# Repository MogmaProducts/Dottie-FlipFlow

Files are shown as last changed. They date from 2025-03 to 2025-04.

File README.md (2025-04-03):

# Dottie FlipFlow


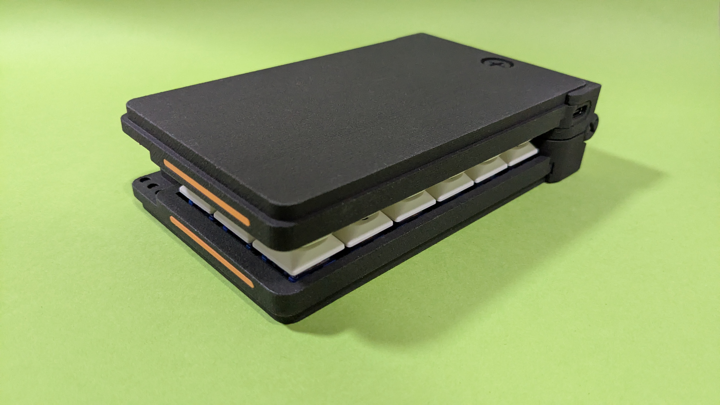
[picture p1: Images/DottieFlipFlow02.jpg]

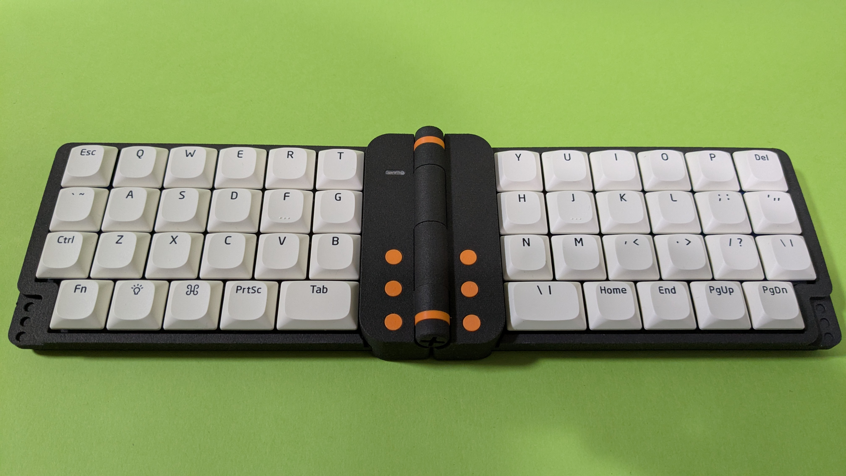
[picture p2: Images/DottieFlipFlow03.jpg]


[ShopSite](https://mogma-products.booth.pm/items/6564751)

## What's Dottie FlipFlow
- The keyboard has a hinge in the center, allowing it to fold up.
- It is thin and can be equipped with Choc V1, V2, and Lofree key switches.
- This keyboard only supports lowprofile keycaps.
- We are very sorry, but this keyboard is not released as open source.

## What is this repository?
- This is a repository for publishing files and manuals required by users.

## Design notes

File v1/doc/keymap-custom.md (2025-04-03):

# キーマップの設定

キーマップの設定はRemapで行います。  

1. Dottie FlipFlowをPCに接続します。

1. ブラウザより以下のサイトにアクセスしてください。  
https://remap-keys.app/configure

## 初回やること
初回アクセスの場合はキーボードへの接続が必要となるため、Dottie FlipFlowを選択して接続を行ってください。
1. `+キーボード` をクリック
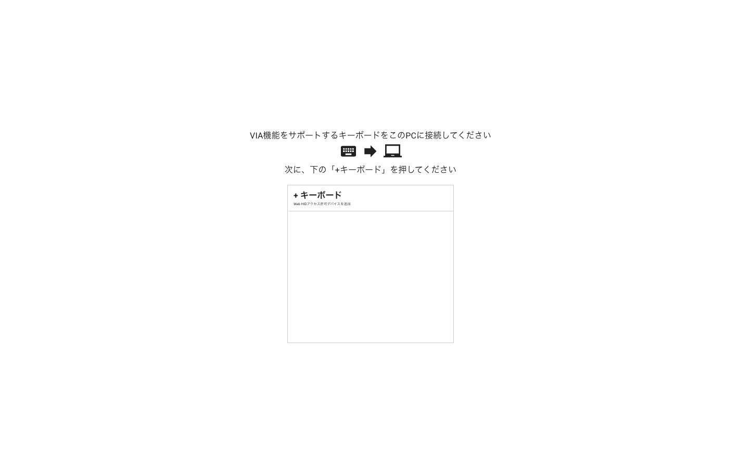
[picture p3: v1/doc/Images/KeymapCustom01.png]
初回アクセスの画面

1. `mogma_products/dottie_flipflow` を選択して`接続`をクリック
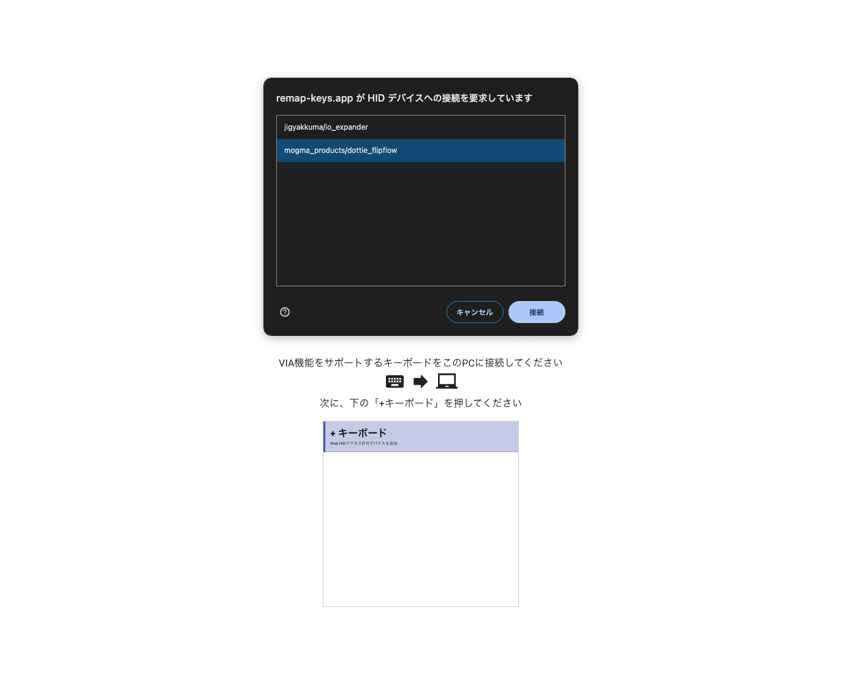
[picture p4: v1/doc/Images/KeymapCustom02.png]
デバイス選択


## キーマップ設定
1. キーコンフィグ画面が開いたらお好みのキーマップに変更してください。
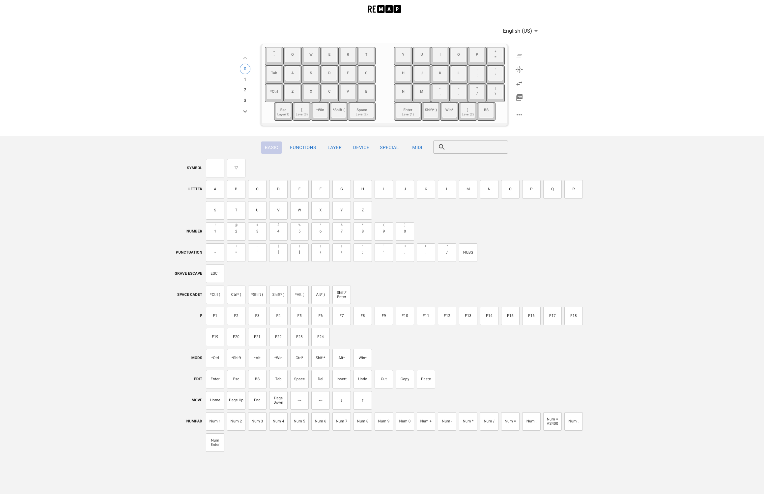
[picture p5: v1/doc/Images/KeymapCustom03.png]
キーコンフィグ画面


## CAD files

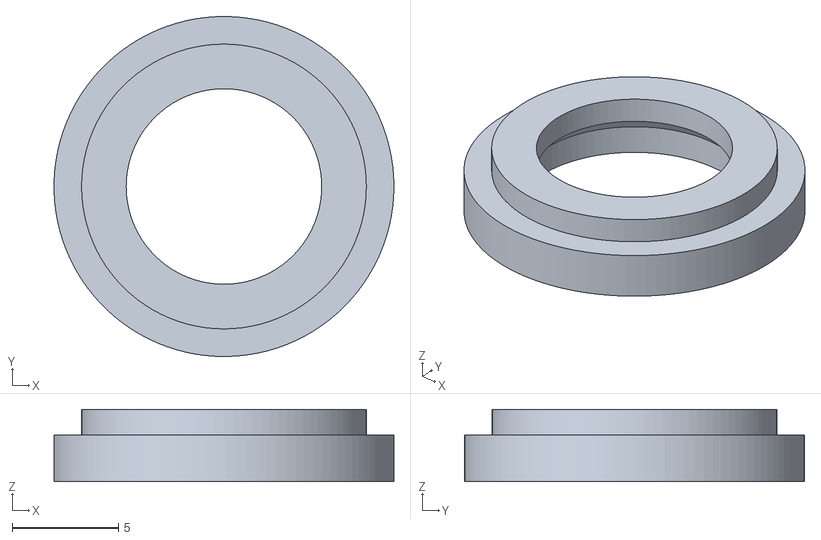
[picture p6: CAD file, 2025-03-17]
v1/Accessories/Dottie_ring_standoff.stl
16.0 x 16.0 x 3.40

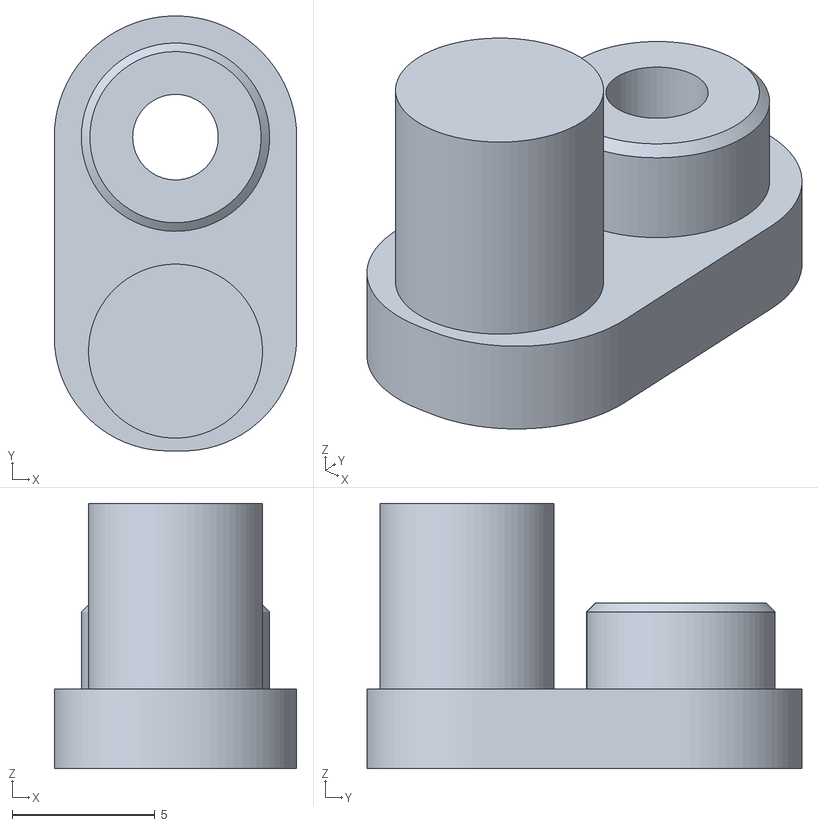
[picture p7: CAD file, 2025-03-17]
v1/Accessories/Dottie_dots_bit.stl
8.50 x 15.2 x 9.30

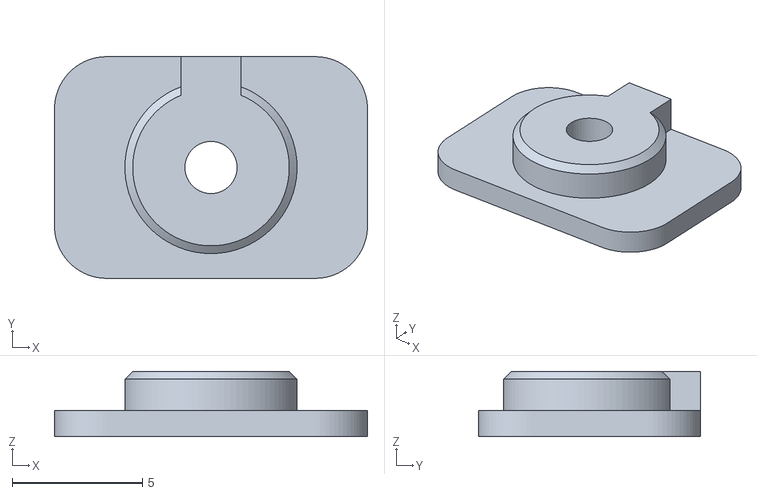
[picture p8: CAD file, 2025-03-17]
v1/Accessories/Dottie_dots_cover.stl
12.0 x 8.50 x 2.50

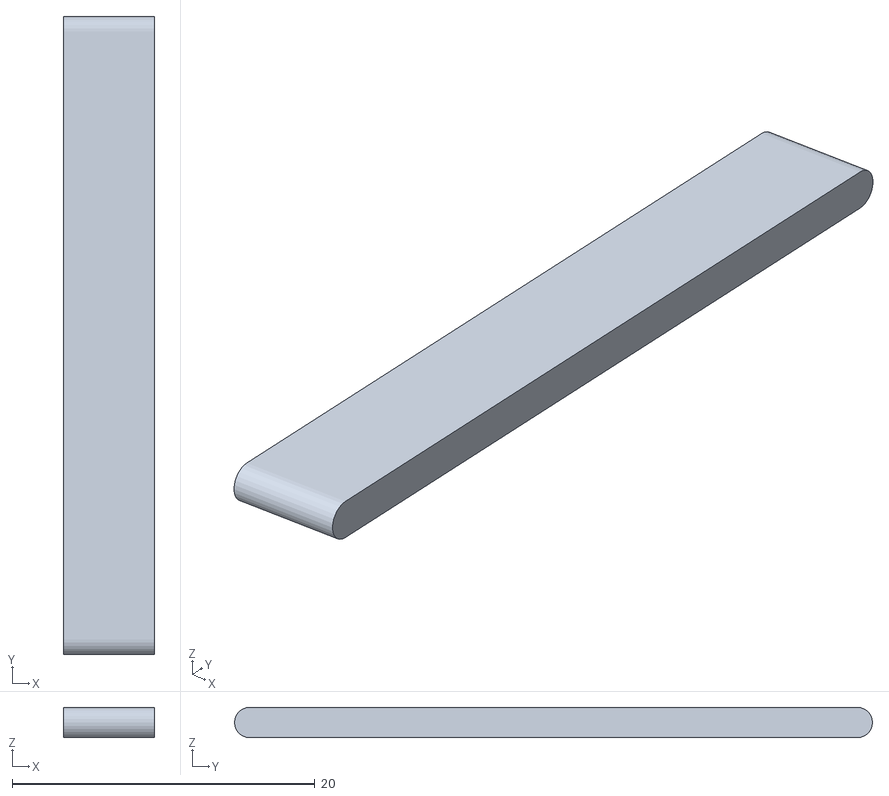
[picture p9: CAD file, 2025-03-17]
v1/Accessories/Dottie_sideline.stl
6.00 x 42.1 x 2.00

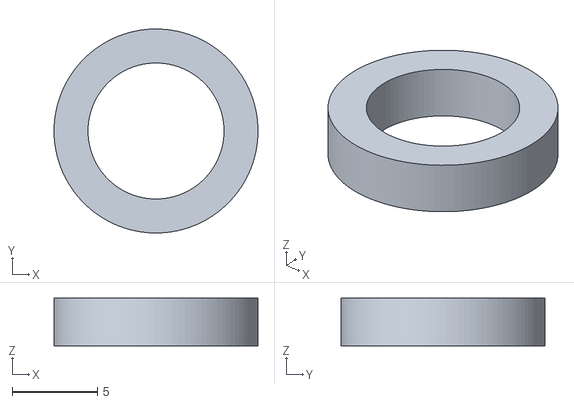
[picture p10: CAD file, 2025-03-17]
v1/Accessories/Dottie_washer.stl
12.0 x 12.0 x 2.80

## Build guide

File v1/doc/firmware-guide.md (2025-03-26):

# ファームウェアの設定

## ファームウェア

ビルド済ファームウェア
https://github.com/MogmaProducts/Dottie-FlipFlow/tree/main/v1/file

ビルドするためのソースコード
https://github.com/MogmaProducts/qmk_firmware/tree/keyboard/dottie-flipflow

## 購入後のRP2040 Zeroにビルドファイルを書き込む

購入して何もQMKのファームウェアが書き込まれていない場合は以下の手順で書き込みを行ってください。

1. ビルド済ファームウェアを作業するPCにダウンロードする。
1. RP2040 ZeroのBOOTボタン(並んでいるボタンの左側)を押しながらPCに接続されているUSBケーブル(Type-C)を接続する。
1. USBストレージとして認識されたのが確認できたらビルド済ファームウェアに保存する。
1. ファイル格納後、USBキーボードとして認識されることを確認する。

## ビルドファイルを書き換える

手順としては[購入後のRP2040 Zeroにビルドファイルを書き込む](#購入後のrp2040-zeroにビルドファイルを書き込む)と同様ですが、ファームウェアを書き込んだ後はRP2040 Zeroではなく、**キーボードの左1.5Uキーを押しながらUSBケーブルを差し込む**ことでUSBストレージとして起動します。  
ケースから出すことなくBOOT出来るので少し楽ができます。

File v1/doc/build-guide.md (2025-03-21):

# Dottie FlipFlow V1 ビルドガイド
## パーツリスト
### 共通パーツ
| Parts | Amount | Description |
| --- | --- | --- |
| PCB | 左右1枚ずつ |　キースイッチを取り付ける基板 |
| 本体ケース | 左右1つずつ | PCBを収納するケース |
| ケースヒンジ | 左右1つずつ | 左右の本体ケースをつなぐヒンジ |
| ヒンジスクリュー | 2 | ヒンジの接合部品 |
| ボトムスクリュー | 2 |　本体ケースとケースヒンジの接合部品 |
| SHケーブル | 1 | 左右PCBを接続するケーブル |
| LEDディフューザー | 1　| LEDを透過させるクリアパーツ |
| ヒンジワッシャー | 各色2 | ヒンジとヒンジスクリューに挟むワッシャー兼装飾部品 |
| ケーススペーサー | 各色2 | ケースとPCBの間に入れるスペーサー兼装飾部品 |
| マグネットDots | 各色6 | ヒンジ上部に仕込むマグネットのフタ兼装飾部品 |
| マグネットカバー | 2 | ヒンジ横に仕込むマグネットのフタ |
| サイドバー | 各色2 | ケースベゼルのスリットに差し込む装飾部品 |
|マグネット | 8 | 6 x 2 mmのマグネット |

※付属のマグネットは磁力が弱いため、100円ショップなどで購入いただくのをおすすめします。

### Standardキット(はんだ付けが必要)に含まれるパーツ
Easyキット(はんだ付け済のキット)はこれらのパーツは既にはんだ付けされているため、パーツとしては同梱されていません。
| Parts | Amount | Description |
| --- | --- | --- |
| RP2040 Zero(相当品) | 1 | マイコン |
| Kailh Choc ホットスワップソケット | 50 | キースイッチを脱着可能にするためのソケット |

### 使用者で用意するもの
| Parts | Amount | Description |
| --- | --- | --- |
| キースイッチ | 46 | Kailh Choc V1,V2, Lofree Low Profileのいずれかに対応したもの |
| キーキャップ | 1U x 44, 1.5U x 2 | Low Profileのキーキャップのみ対応 |
| ゴム足 | 8 | 装着しなくても使えますが、好みに応じてゴム足を貼り付けてください |
| USBケーブル | 1 | キーボード側はUSB Type-Cが必要 |

### 組み立てに必要な工具
| Tool | Description |
| --- | --- |
| プラスドライバー | 軸が5.5〜7mmくらいのもの |
| ニッパーもしくはカッターナイフ | PCBを切り取るために使用 |
| やすり | PCBを削るために使用 |
| ピンセット | 細かい部品をつまんだり通電確認用にあると便利 |

## 組み立てる前に
### 注意事項
- 本キーボードはヒンジ部と底面部に3Dプリント製のネジを採用していますが、強く締めるとネジ部分が固く締まったりケースが破損する可能性がありますのでご注意ください。
- 本キーボードに強い衝撃を加えると破損する恐れがあるため、特に持ち運びの際にはご注意ください。
- Standard Kitにおいても一部の部品が既にはんだ付けされていますので、はんだ付け作業の際ははんだゴテではんだ付け済みの部品に触れないように注意してください。
- 市販品のパーツ(RP2040 Zero(相当品)、ホットスワップソケット)はサービスとして添付しておりますので、万が一不良があった場合は購入者様にてご用意をお願いします。
- キーボードケースなどのSLSによる3Dプリントの部品は製造プロセス上、原料の粉末が付着している可能性があるため、その場合は布なので拭き取ってください。
- SLSによる3Dプリントの部品は形状の関係で反りなどの歪みがある場合がありますが、使用上問題ない精度であると確認したものを販売しています。気になる場合はドライヤーやヒートガンなどで温めて歪みを修正してください。

## ビルド手順
Easy Kitを購入の方ははんだ付けの手順は飛ばして本体組み立てに進んでください。

### はんだ付けの前の準備
はんだ付けの前に動作確認を行います。はんだ付けをした後に動作不良が発覚した場合、手戻りの作業に大きく時間を取られてしまうためです。  

1. RP2040 Zeroを取り出し、BOOTボタンを押下しながらPCに接続したUSBケーブル(Type-C)を接続します。
1. USBストレージとして認識されることを確認します。
1. RPI-RP2と認識されたUSBストレージにビルド済みファイルを保存します。
1. 再起動後にLEDが点灯すれば動作確認と下準備は完了です。

### はんだ付け
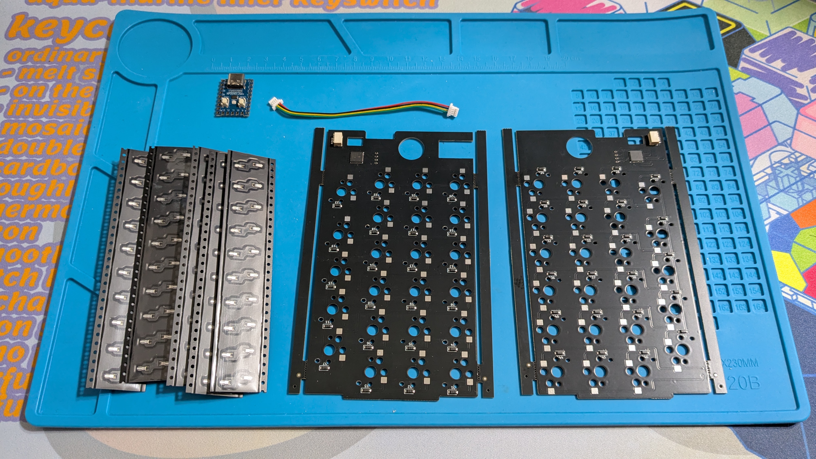
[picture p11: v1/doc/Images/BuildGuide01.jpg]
はんだ付け作業で使うもの

1. PCBの不要な部分を切り取ります。工具を使わずに切り取ることも出来ますが、ニッパーなどで切り取るときれいに仕上がります。
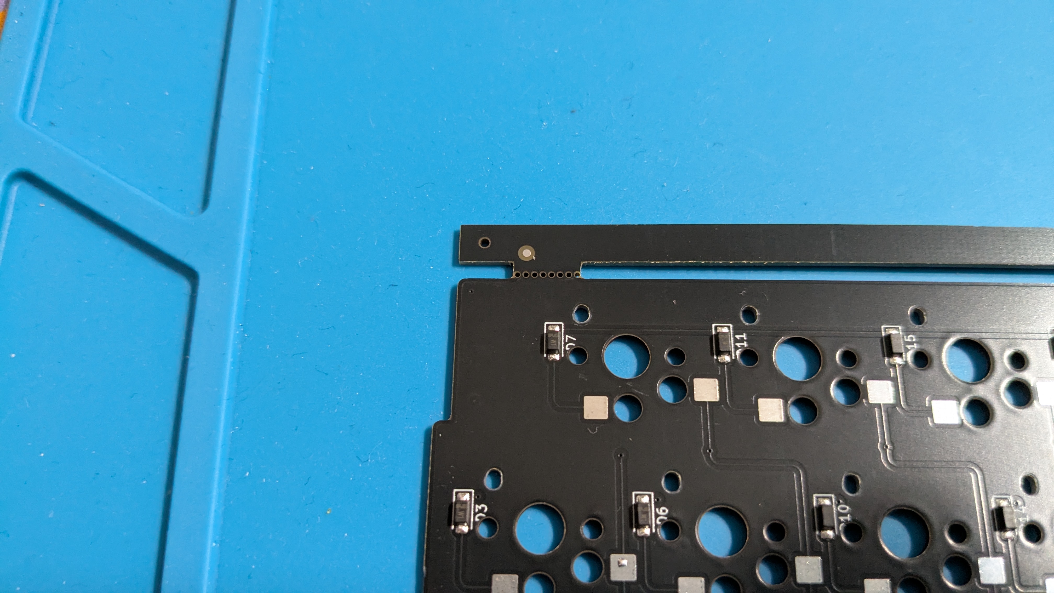
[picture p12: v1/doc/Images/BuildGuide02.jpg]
切り取る前

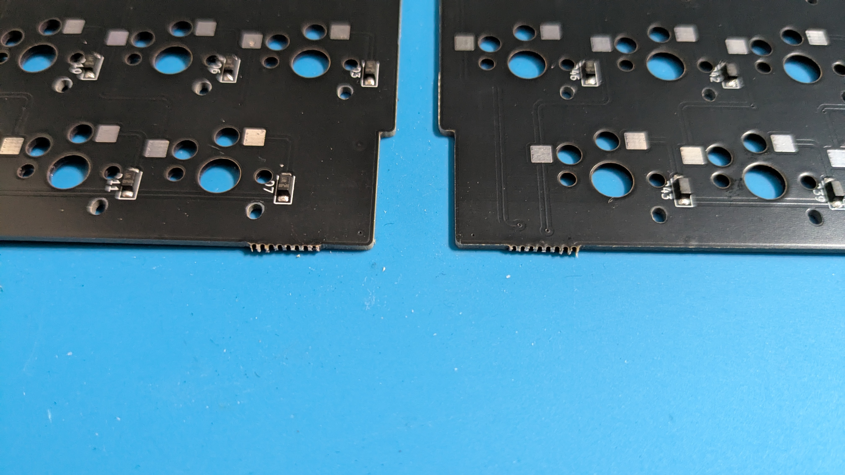
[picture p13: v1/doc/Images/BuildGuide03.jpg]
切り取った後

1. 切断面をやすりで削ります。ある程度削れていればよいです。
削った後
1. ホットスワップソケットのはんだ付けをします。はじめに、注意点としてソケットには向きがあります。角がある方が外側(つまりは左側)に来るようにはんだ付けします。
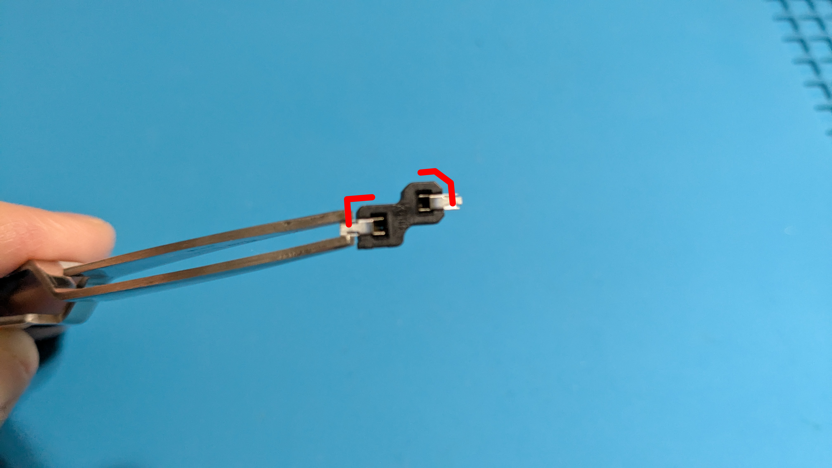
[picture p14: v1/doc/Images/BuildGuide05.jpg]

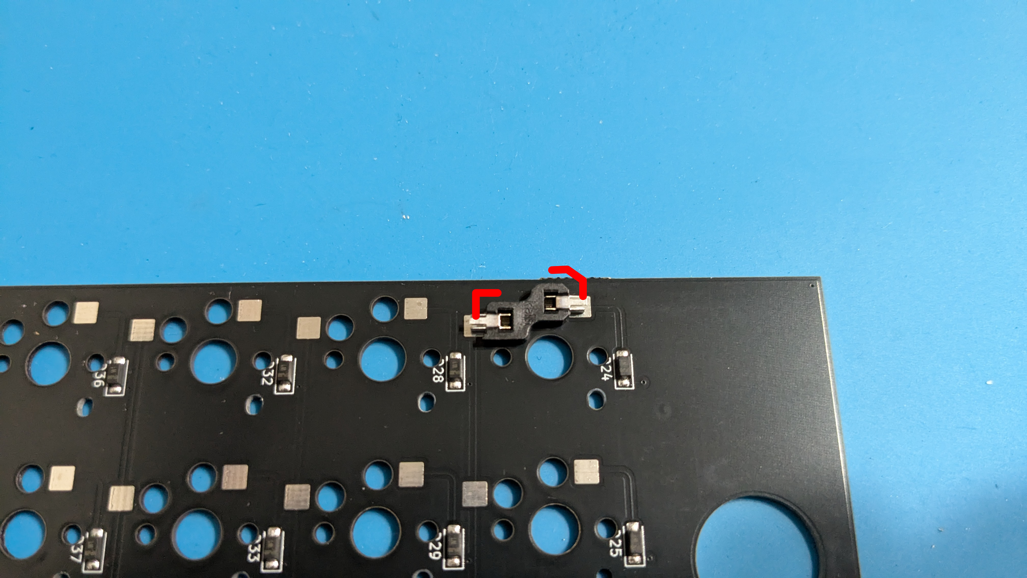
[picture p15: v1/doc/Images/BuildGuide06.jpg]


1. ホットスワップソケットをPCBに並べます。ホットスワップソケットはPCB裏面にはんだ付けします。


1. ホットスワップソケットの両サイドをはんだ付けします。  
コツとしては片側だけはんだ付けした後に乗せたはんだを再加熱してホットスワップソケットを押さえるとしっかりとはんだ付けができます。  
両サイドを先にはんだ付けしてしまうと浮いていた場合に修正が難しいので片側ずつ丁寧にはんだ付けを行います。
Right側の裏面
Left側の裏面
この写真だとすべてをはんだ付けしてから浮いていないか確認していますが、これは間違いです。慣れないうちは1つ1つ確認しながらはんだ付けを行います。
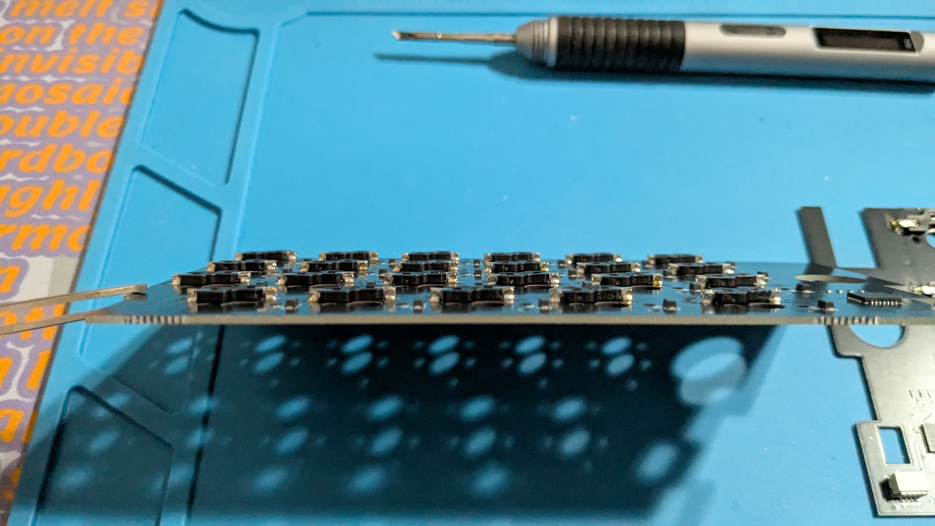
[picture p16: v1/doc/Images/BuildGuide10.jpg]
浮いてないか角度を変えてしっかり確認


1. RP2040 Zeroをはんだ付けします。RP2040 ZeroはPCB表面にはんだ付けしてください。  
はんだ付けをする位置は意図的にずらしているので画像を参考に配置してください。
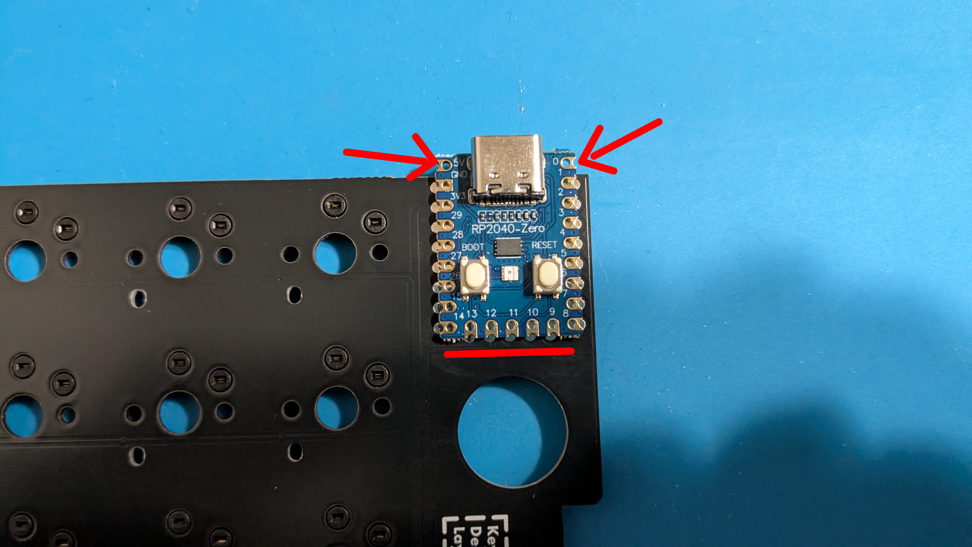
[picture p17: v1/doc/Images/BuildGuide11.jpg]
矢印の箇所はPCBに乗せない、おしりの部分に合わせる

1. クリアランスを確認するために1箇所だけはんだ付けし、その後ケースに入れてUSBコネクタが干渉しないか確認してください。  
干渉する場合は位置調整をしてください。
コンパクトの代償にクリアランスが厳しくてごめんなさい
1. 位置が確定したら残りの部分もはんだ付けします。
使用するIOが少ないので画像では全部ははんだ付けしてません

はんだ付けの作業はここで終了です。続きまして本体の組み立てです。

### 本体組み立て

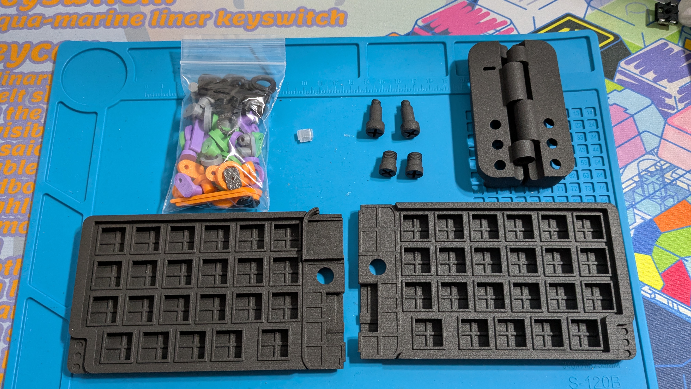
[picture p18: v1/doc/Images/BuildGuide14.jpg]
本体の組み立て作業で使うもの

1. ケースヒンジ(左側)を裏返し、LEDディフューザーを差し込みます。抜けないようクリアランスがシビアになっているため破損させないようゆっくりと押し込んでください。
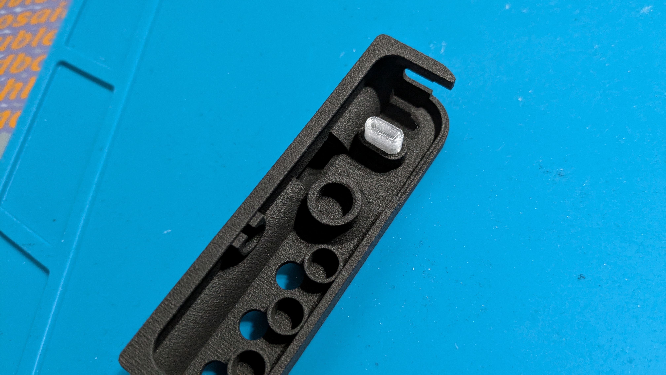
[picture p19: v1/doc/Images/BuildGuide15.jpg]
固いのでグッと押し込みます


1. ヒンジスクリューにヒンジワッシャーを差し込みます。  
ヒンジワッシャーは色違いを用意していますのでお好きなカラーをお選びください。
グッと押し込みます

1. 左右のケースヒンジを組み合わせ、ヒンジスクリューで止めます。  
このとき、強く締めないでください！ヒンジ部はネジの圧力によって破損する恐れがあるので、ヒンジを開閉させながら締め具合を微調整してください。

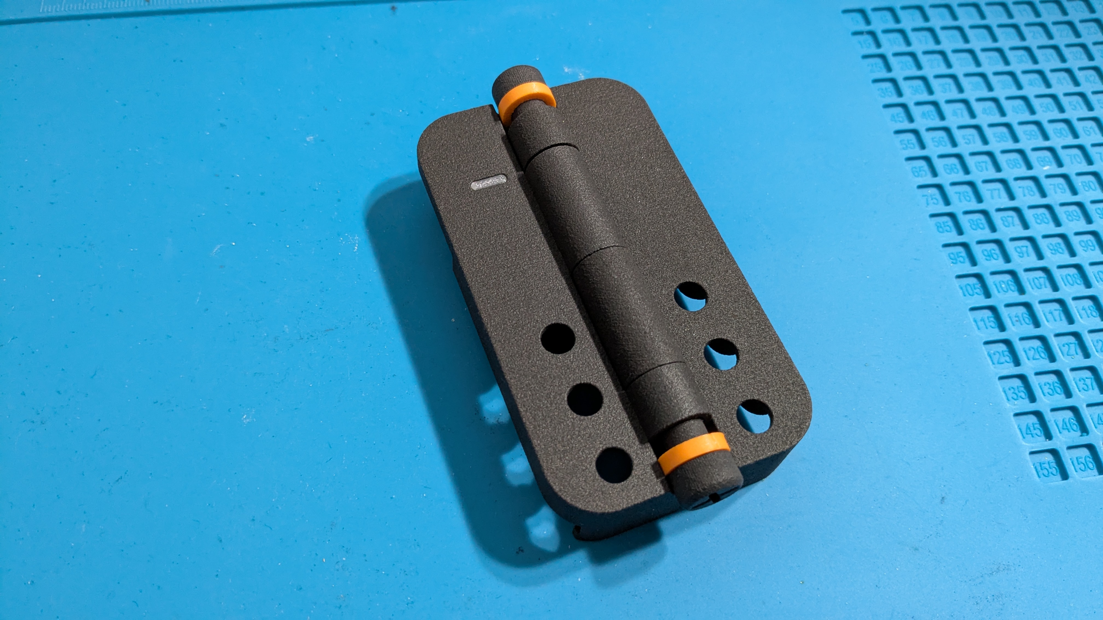
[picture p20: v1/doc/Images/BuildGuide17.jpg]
ヒンジスクリューを優しく締めます

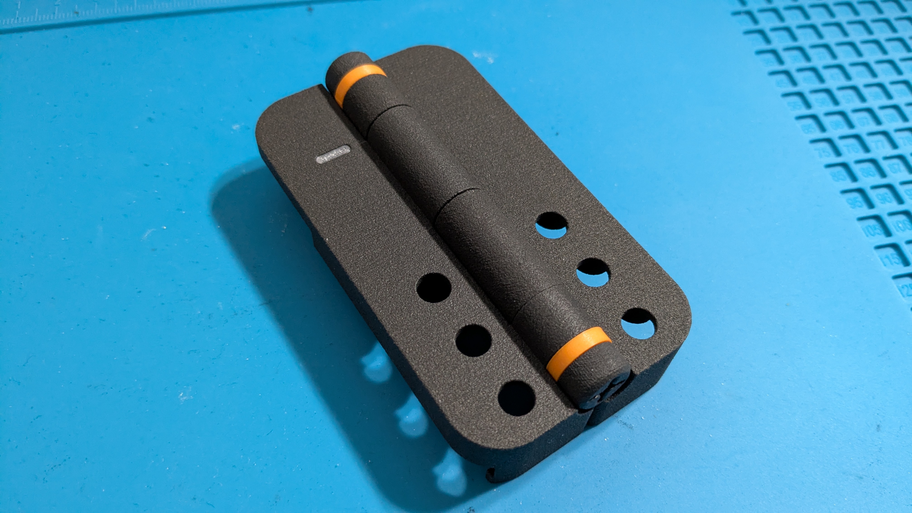
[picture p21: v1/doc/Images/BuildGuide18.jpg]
フェザータッチで締めてください


1. マグネットDotsを取り付けます。このとき、マグネットがある場合は先に赤丸の箇所にマグネットを入れてからマグネットDotsを取り付けてください。  
マグネットを利用する場合は磁力でくっつくよう方向を確認しながら入れてください。
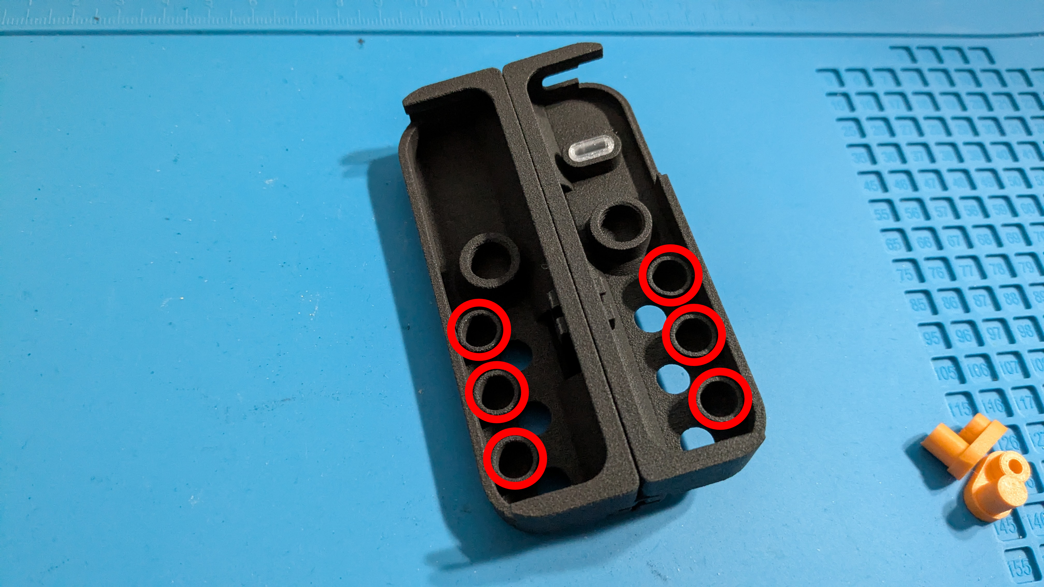
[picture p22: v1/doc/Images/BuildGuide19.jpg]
赤丸はマグネットを入れる箇所

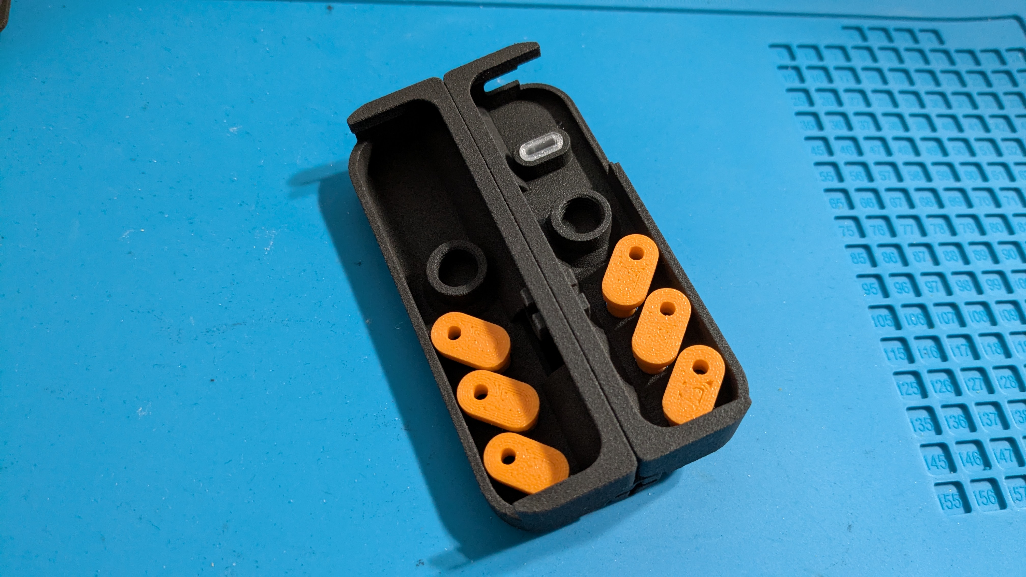
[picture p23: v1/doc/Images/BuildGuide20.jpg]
お好きなカラーのマグネットDotsをお選びください

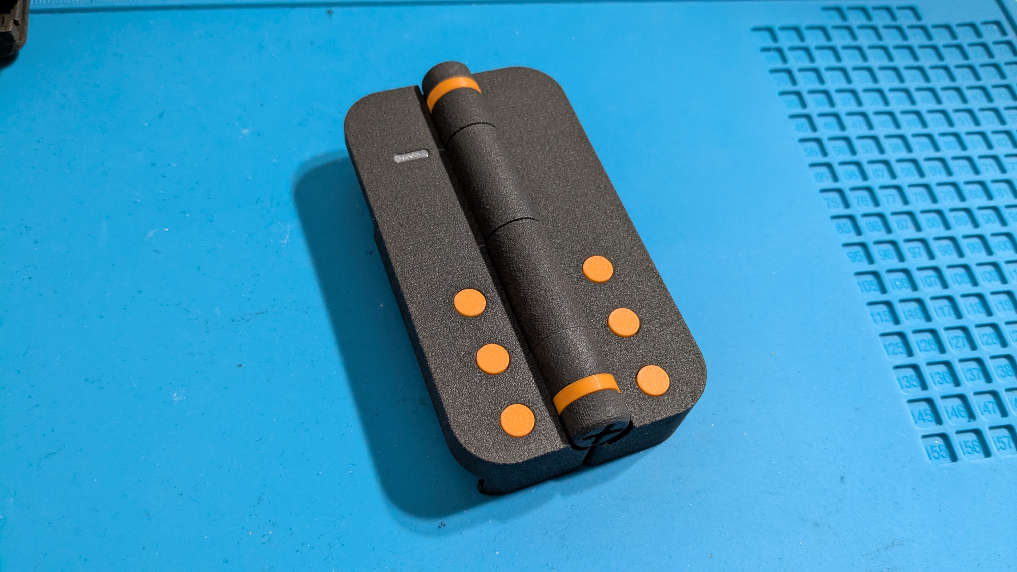
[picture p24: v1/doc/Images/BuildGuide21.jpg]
表面からみるとこんな感じ


1. ケースヒンジの横部にマグネットカバーを取り付けます。このとき、マグネットがある場合は先に赤丸の箇所にマグネットを入れてからマグネットカバーを取り付けてください。  
マグネットを利用する場合は磁力でくっつくよう方向を確認しながら入れてください。
赤丸はマグネットを入れる箇所
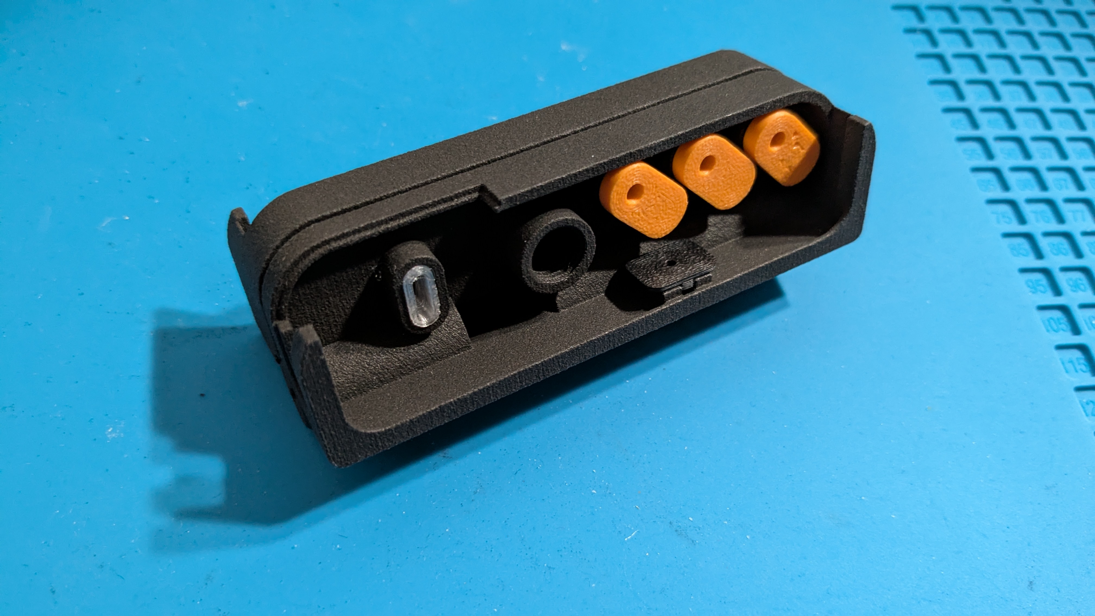
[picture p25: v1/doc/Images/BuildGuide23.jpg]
マグネットカバーを装着するとこんな感じ


1. サイドバーを装着します。ケースサイドのスリットはサイドバーを装着しなくても見栄えがいいのでこちらについてはお好みで装着してください。  
装着する場合はサイドバーをスリットの形状に合わせて押し込みます。

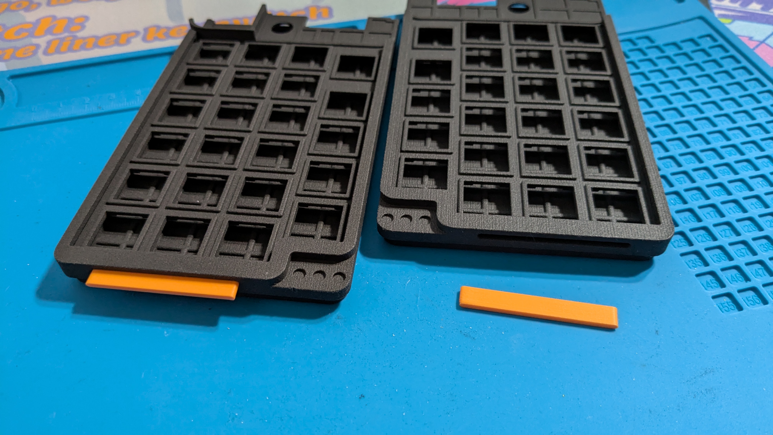
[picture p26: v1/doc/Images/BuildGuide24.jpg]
軽く差し込んでから

グッと押し込む

1. SHケーブルをPCBに差し込みます。その前に、差し込むコネクタの向きを確認します。  
SHケーブルのコネクタは金具が見えている面とプラスチック面がありますが、写真にある通りプラスチック面がみえるように差し込みます。
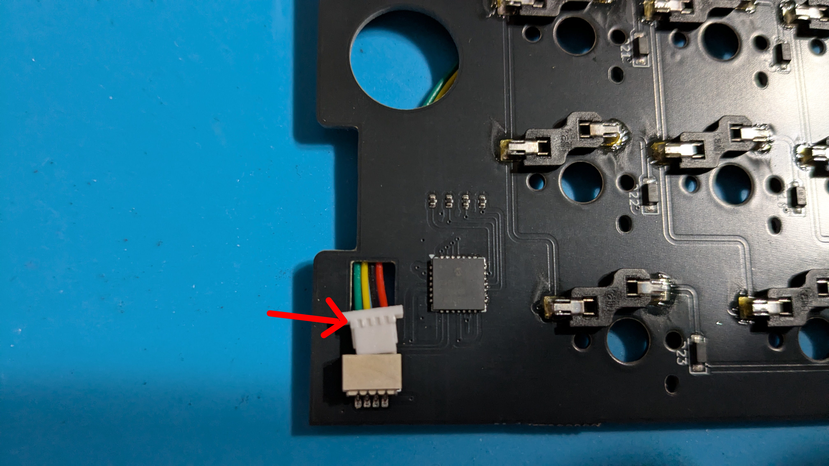
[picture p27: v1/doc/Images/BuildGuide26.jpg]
差し込む向きを間違えると故障の恐れがあるため注意が必要です

向きがあってるとしっかりと刺さります
PCBの左側にSHケーブルを差し込んでからケーススペーサーを乗せます。ケーブルを差し込みましたら四角のホールにケーブルを通しておきます。
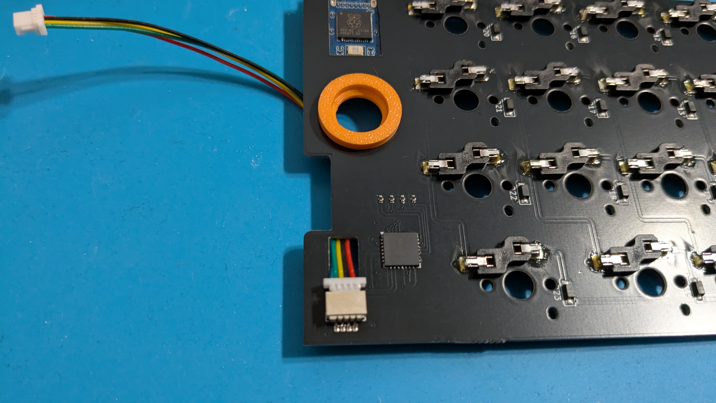
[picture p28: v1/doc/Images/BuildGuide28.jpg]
お好きなカラーのケーススペーサーをお選びください


1. PCBを置いたまま本体ケース(左側)をPCBに差し込みます。一気に差し込むのではなく2/3くらいまで差し込んでください。  
このとき、本体ケースにPCBが入りづらい場合は何度か抜き差しをして馴染ませてください。もしくはPCBの切り取り箇所が引っかかっていないかも合わせて確認してください。


1. PCBを本体ケース奥まで差し込みます。ケーススペーサーがズレていないことも確認してください。
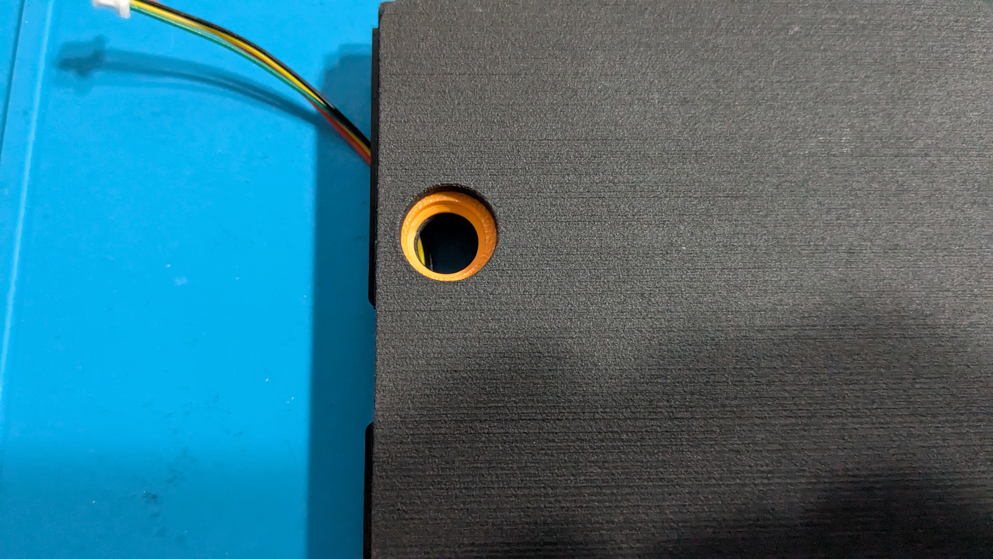
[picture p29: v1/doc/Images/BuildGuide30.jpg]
奥まで差し込むとケーススペーサーと本体ケースの穴の位置が合います

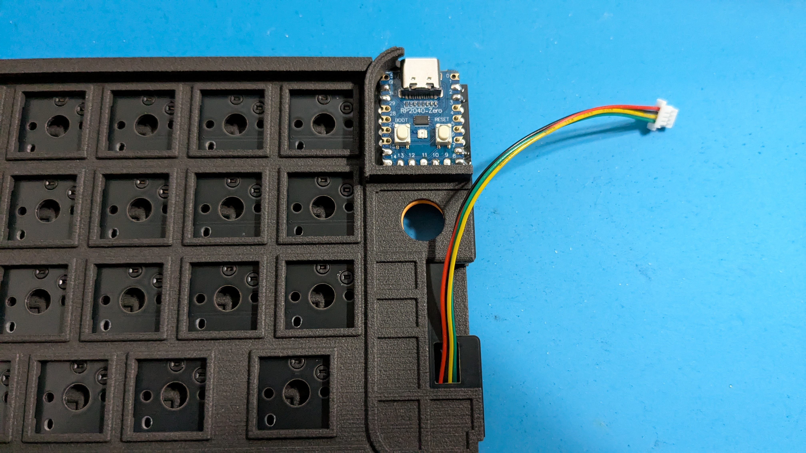
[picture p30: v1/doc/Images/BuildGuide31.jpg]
ケーブルを挟み込んでいないか表面からも確認する


1. SHケーブルをケースヒンジ内に通します。赤囲み箇所の切り欠きにケーブルを挿入します。
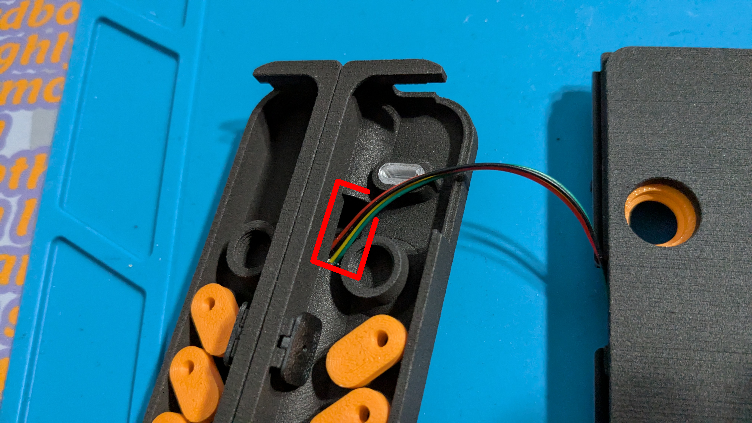
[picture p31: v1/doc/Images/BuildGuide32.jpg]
ほんとにケーブル通るの？となりそうですが、とりあえず突っ込んでみる

ケーブルが反対側から出ていることを確認します。うまく出てこない場合はピンセットなどでやさしく引き上げてください。  
強くひっぱるとコネクタ部分が破損するので注意してください。
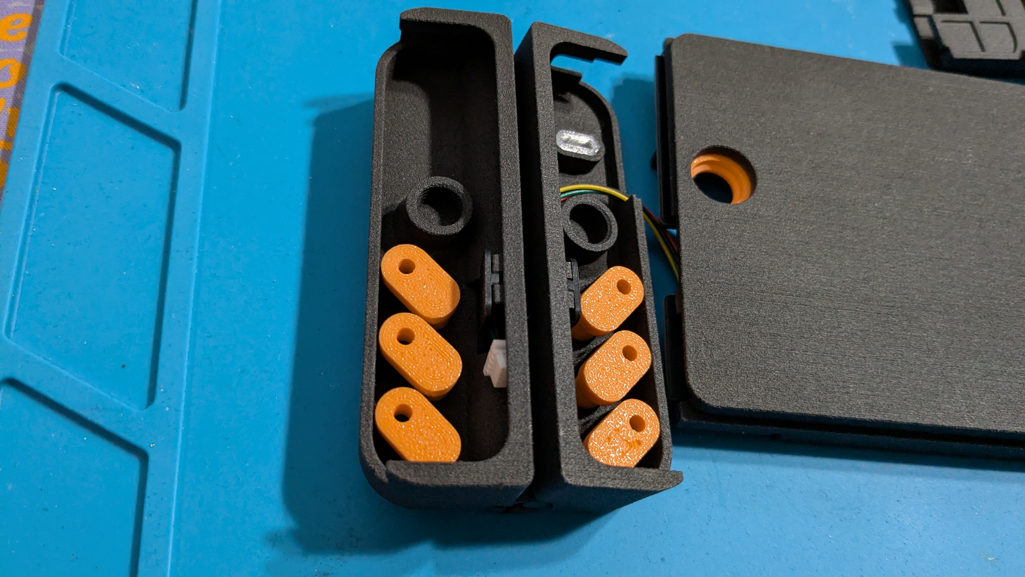
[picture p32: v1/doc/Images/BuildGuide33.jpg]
意外とコネクタがスッと出てくる


1. SHケーブルが反対側に通ったら本体ケースとケースヒンジに差し込みます。このとき、ケーブルが抜けないよう注意しながら本体ケースを差し込んでください。
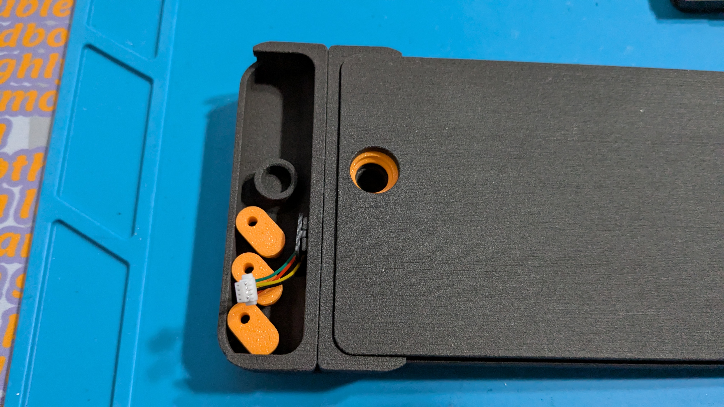
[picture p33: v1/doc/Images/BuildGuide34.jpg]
合体っっ！！！


1. 本体ケースにボトムスクリューで止めます。ヒンジスクリューと同様、締めすぎに注意してください。
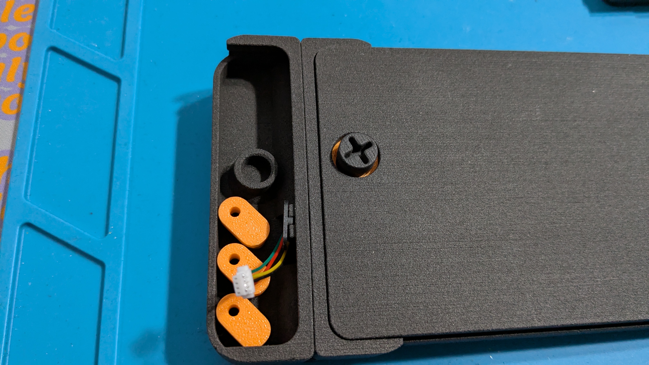
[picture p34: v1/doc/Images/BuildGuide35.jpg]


1. PCB(右側)にSHケーブルを差し込みます。左側と同様、プラスチック面がみえるようにして差し込んでください。ケーブルを差し込んだらケーススペーサーを置きます。
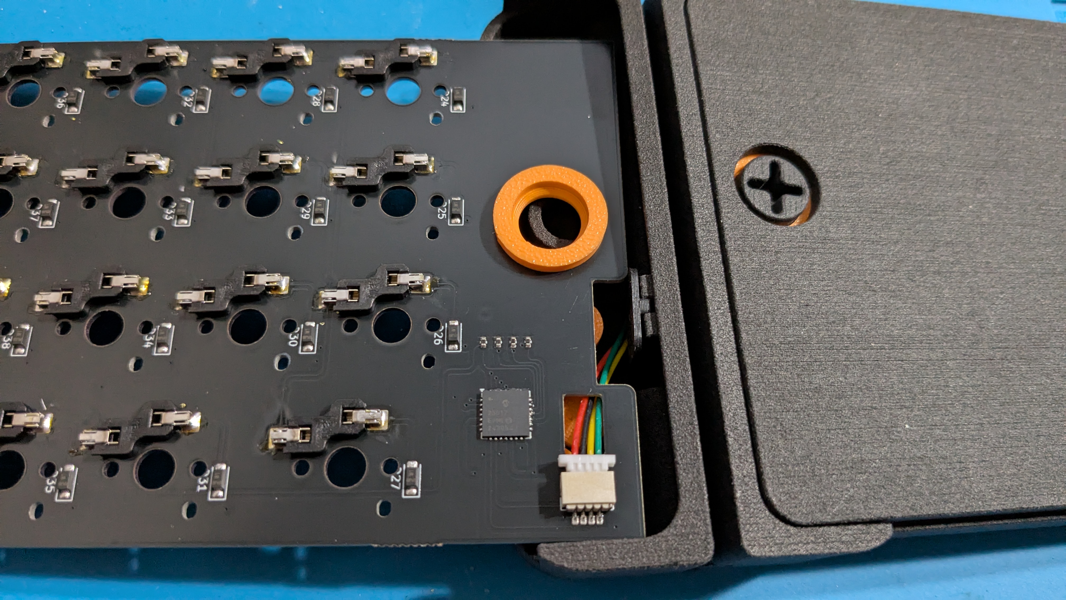
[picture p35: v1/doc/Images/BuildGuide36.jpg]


1. PCB(右側)に本体ケースを差し込みます。手順は左側と同様です。差し込んだら同様にボトムスクリューで止めてください。
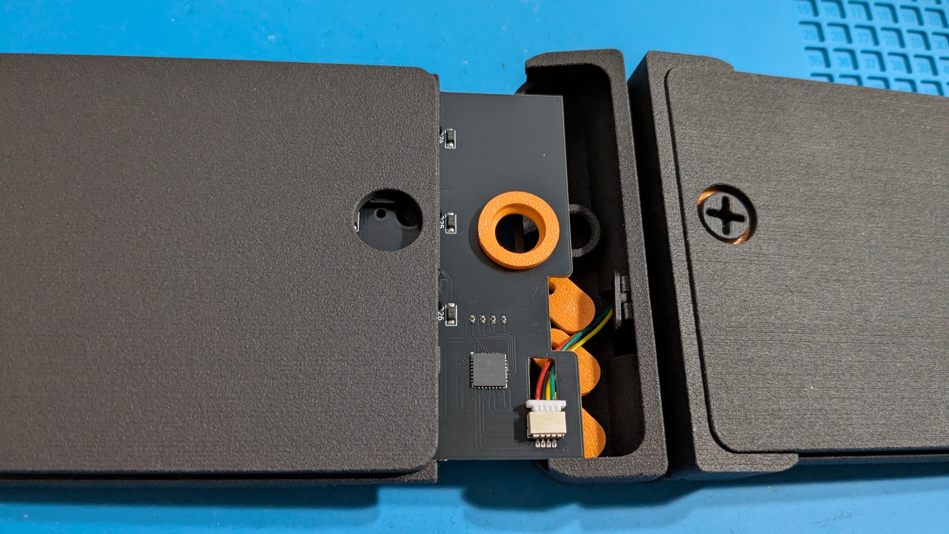
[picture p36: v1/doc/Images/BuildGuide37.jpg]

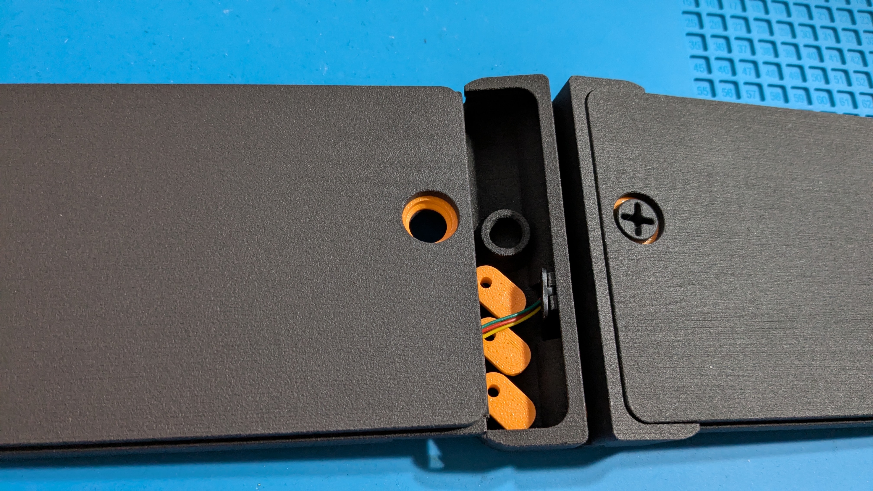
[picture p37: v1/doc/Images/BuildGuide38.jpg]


1. これで完成です！
お好きなキースイッチとキーキャップを装着してください！！ 
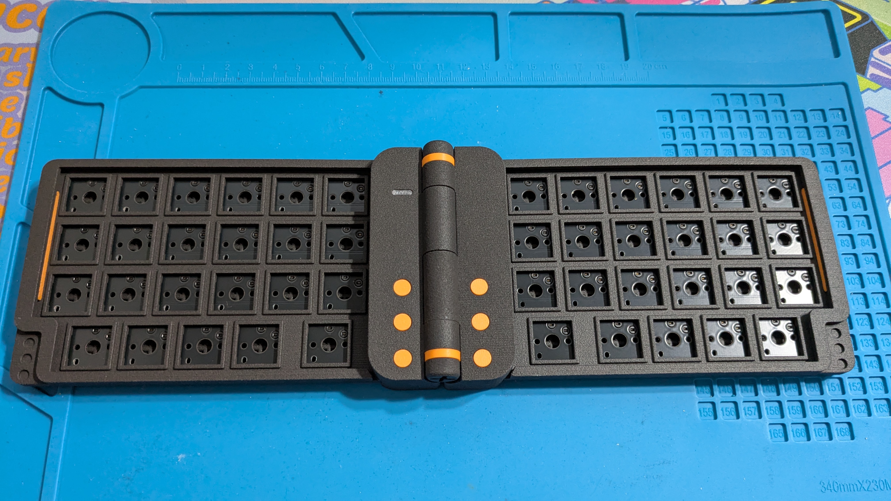
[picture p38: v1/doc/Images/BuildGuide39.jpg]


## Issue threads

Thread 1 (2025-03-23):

[質問]ビルドガイドについて

hmhm01, 2025-03-23:
@MogmaProducts

素晴らしいキーボードの作成ありがとうございます！
先日、キーケット2025にて Dottie FlipFlow を購入させていただいたものです。

素人質問でしたら申し訳ないのですが、2点質問があります。
X (https://x.com/MogmaProducts) にて DM できなさそうだったので、GitHub 上にて失礼します。

## 1点目: ビルドファイルについて
> https://github.com/MogmaProducts/Dottie-FlipFlow/blob/main/v1%2Fdoc%2Fbuild-guide.md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

こちらに記載のある「ビルドファイル」はどちらから取得可能でしょうか？

## 2点目: RP2040 Zero のはんだ付け箇所について
> https://github.com/MogmaProducts/Dottie-FlipFlow/blob/main/v1%2Fdoc%2Fbuild-guide.md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

> 位置が確定したら残りの部分もはんだ付けします。

こちらの画像を確認すると、左右の中央にあるそれぞれ4つの穴ははんだ付けをされていないようですが、実際作成する際もはんだ付けを避けたほうがよいでしょうか。

---

私のほうでビルドガイドの確認不足でしたら大変申し訳ないのですが、ご回答いただけますと幸いです。

hmhm01, 2025-03-24:
@jigyakkuma

ご確認、ファイルのご準備ありがとうございます！
助かりました🙇‍♂️

はんだ付けに失敗したのか、すべてのキーが反応しないため、まだ動作確認はできていないのですが、ひとまず確認させていただきたかったことは確認できましたので、こちらは close させていただきます。
ありがとうございました！

Closed 2025-03-24.

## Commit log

2025-03-17 Added Accessories 3D model file
    [Dottie_dots_bit.stl, Dottie_dots_cover.stl, Dottie_ring_standoff.stl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]
2025-03-20 注意事項を追記
2025-03-20 キーマップ設定のドキュメント追加
2025-03-21 マグネットについての追記
2025-04-03 Remapにキーボードを登録したので設定方法の記述を変更した
